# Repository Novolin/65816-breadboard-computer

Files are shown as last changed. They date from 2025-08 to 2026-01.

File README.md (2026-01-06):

# 65816-breadboard-computer
My Personal 65C816 breadboard build, including schematics, etc.

/KiCad contains my schematics/raw kicad files, if you want to laugh at my design.

/Software contains the programs I've written, mostly raw assembly, but I will hopefully have a C compiler up and running eventually.

/Docs will have a variety of documents on the exact nature of each hardware decision and how it works. I'll also be publishing these to a blog on my web zone. 

# Hardware Description:

This system is designed to use modular components, with room for expansion in RAM or I/O, using programmable logic. 

The primary CPU is a W65C816, which handles all logic/program execution. The "Bare Minimum" setup includes 32k of RAM and 32K of ROM space, both of which are placed on the primary controller board. The CPU is driven to 1 MHz by a divided clock oscillator, which provides a 2-phase clock signal, for any devices that may need it.

Expansion is handled through a 2x20 pin slot, so I can use a standard floppy drive cable to send it to a breakout board or other device.

## Graphical Output:

Despite my original intentions to use a z80 to drive a 320x240 display via weird magic bullshit, I have decided to switch to having the CPU directly control the display via the VIA's PORTB, though I will be sharing this with the 16x2 LCD thanks to some Ideas about how to handle I/O. See Docs/Displays for details.

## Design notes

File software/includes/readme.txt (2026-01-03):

This folder contains modules designed for individual components of the build

Remember to check the addresses defined in the structs in each file! Make sure they match real hardware!!

I am using CA65 as my assembler, so code is formatted for that. I'll write a lil baby script to compile on linux, at some point.

IOMEM only goes up to $01800F, the top address of the ACIA.

reminder: update schematic to include the vrom chip!!

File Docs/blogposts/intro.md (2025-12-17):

# 65C816-Based Homebrew Computer! Part one: The beginnings.

I've been following Ben Eater's 6502 homebrew computer[LINK] for a while, and wanted to do something similar myself. Upon discussing things in the Usagi Electric discord, I decided to use a W64C816S, the successor to the 6502, for a few reasons. First of all: it should be drop-in compatible with Ben's design (at least the early stages). Once I get my feet wet, I can branch out and do a lot more. Secondly, getting a 6502 would have been a whopping $2 less than an '816, so I might as well get the more powerful option, and have room to grow and play around.

## Goals:
At the start, my goals were vague, just to make something that worked, but now I've solidified on a concept:
1. Have a functional computer 
2. Allow connection via serial to another system
3. Have a graphical and text display
4. Enable future expansion/tinkering
    - Human Interface Devices of some form
    - Swapping of graphics/serial/whatevs
5. Get some PCBs made.

### Goal 1: Have a functioning computer.
This is a simple ask: it should be able to run the code that is placed on it, and do stuff. I'm not asking for perfection, but just for it to work. Arguably, this is the hardest part to actually achieve.

### Goal 2: Serial Connections
I want to communicate with the computer beyond inserting a new ROM chip, allowing for new programs/etc. A serial connection, using the 65C51 SIA is the best option, since it's in the ecosystem and has good documentation available for it. While using an RS-232 port and UART-to-usb or whatever is an option if I wanted to keep the hardware Authentic, I'm going to be lazy and just use an Arduino Micro as a USB serial adapter. This eases the adapter headaches, since it's able to do the USB -> serial translation, and it's cheap. If I get bitten by the retro-communications bug, I can figure out some other adapter situation and drop it in for ease of use. 

### Goal 3: Graphical and Text Display
Having a system that communicates only via serial is not what I am hoping for with this project. I want to be able to see/read things on a screen, and I purchased a 20x4 LCD display for this project, and repurposed a 320x240 LCD that I've had kicking around for graphical stuff. I've had a few ideas that went bust on this front, and I'll write them up at some point.

### Goal 4: Enable Future Expansion
Making a one-and-done system is a fun project, but I am unable to truly "finish" anything, so my way out for this is to have expansion buses on the system, allowing for more storage, devices, interfaces, etc. These buses will have access to the main CPU lines that I'll need, as well as address/data lines. Since I'm using Programmable Logic Devices as bus controllers, it's easy enough to daisy-chain my ports if needed.

### Goal 5: Get PCBs made
I've never designed a PCB. I did get some made using an open-source design once, but this is a new opportunity for me to expand my skillset, and experiment. It's a scary step, and not the cheapest, but I'm excited to do it. I'll likely use a manufacturing service, instead of etching/machining my own, but even the design process has taught me a lot.
PCBs are also critical for future expansion, since there's only so many breadboards I can manage.

In the short term, my focus has been on the first goal, having *anything* functional, before moving on to dealing with the others. So far, it's eluded me, but I have a hardware tweak that I have yet to test, which should make things fully functional.

## Hardware
As I mentioned at the start, I'm using a W65C816 processor, both due to price similarity to the 6502, but also due to its 24-bit memory addressing.

The 6502 uses a 16-bit memory bus, allowing for up to 64 Kilobytes of addressible memory, be it RAM, ROM, I/O or other stuff. The '816 uses some funky timing and the 8-bit data lines to increase the bus width to 24 bits, allowing for 16 **Mega**bytes of address space. There are also a variety of changes to the processor architecture which allow for 16-bit math, and a number of other changes. I'm not a 6502/65816 wizard, I'm barely what you would call a beginner, but the '816 is just an improved processor at the end of the day.

RAM is currrently divided into 32K SRAM chips, HM62256 clones from Aliexpress, and my total of 5 chips should lead to about 160 Kb of RAM total, which is more than enough for what I'm doing at the moment. 

My ROM is an AT28C256, also off Aliexpress, giving 32K of ROM space. With the addition of serial communications, this should be more than enough to handle the code needed to get things loaded into RAM.

Logic switching is handled by an AT16V8B, a derivitive of the GAL16V8B Programmable Logic Device (PLD). Why PLDs, instead of 74XX logic? Early experiments with graphics adapters led to me needing the ability to latch various control signals, and - once again - sourcing some chips from Aliexpress meant getting 5 of the dang things, so I might as well switch to using 'em. This also eases the burden on addressing expansion signals, since a simple re-flash is all it takes to change the routing (though PLDs do have a limited life-span, and I'll try to avoid re-flashing if possible.)
After a few expansions, it becomes messy as hell to use discrete logic ICs for each change, and that's not something I felt like playing with, especially since early prototyping meant limited breadboard space.

My clock oscillator runs at 16 MHz, which I am dividing three times to bring it to a more managable 2 MHz. I will be able to speed things up in the future, but this should be more than enough for anything I'm planning on.

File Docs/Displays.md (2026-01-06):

# Displays:

There are two displays connected to this system. One is a 320x240 LCD display, connected via SPI, and the other is a 20x4 character display, connected via parallel.

## Display Selection:

Display output is selected using i/o PORTA, with the lower nibble handling the control signals for the text display, and the uppper nibble controlling the graphical display. The plan (as it exists now) is to use defined shortcuts for each type of command, to ensure they do not overlap.

PORTB will send data to the LCD, using the 8-bit communication mode. I may change this in the future to be the 4-bit mode and then I can free up another port for other things.

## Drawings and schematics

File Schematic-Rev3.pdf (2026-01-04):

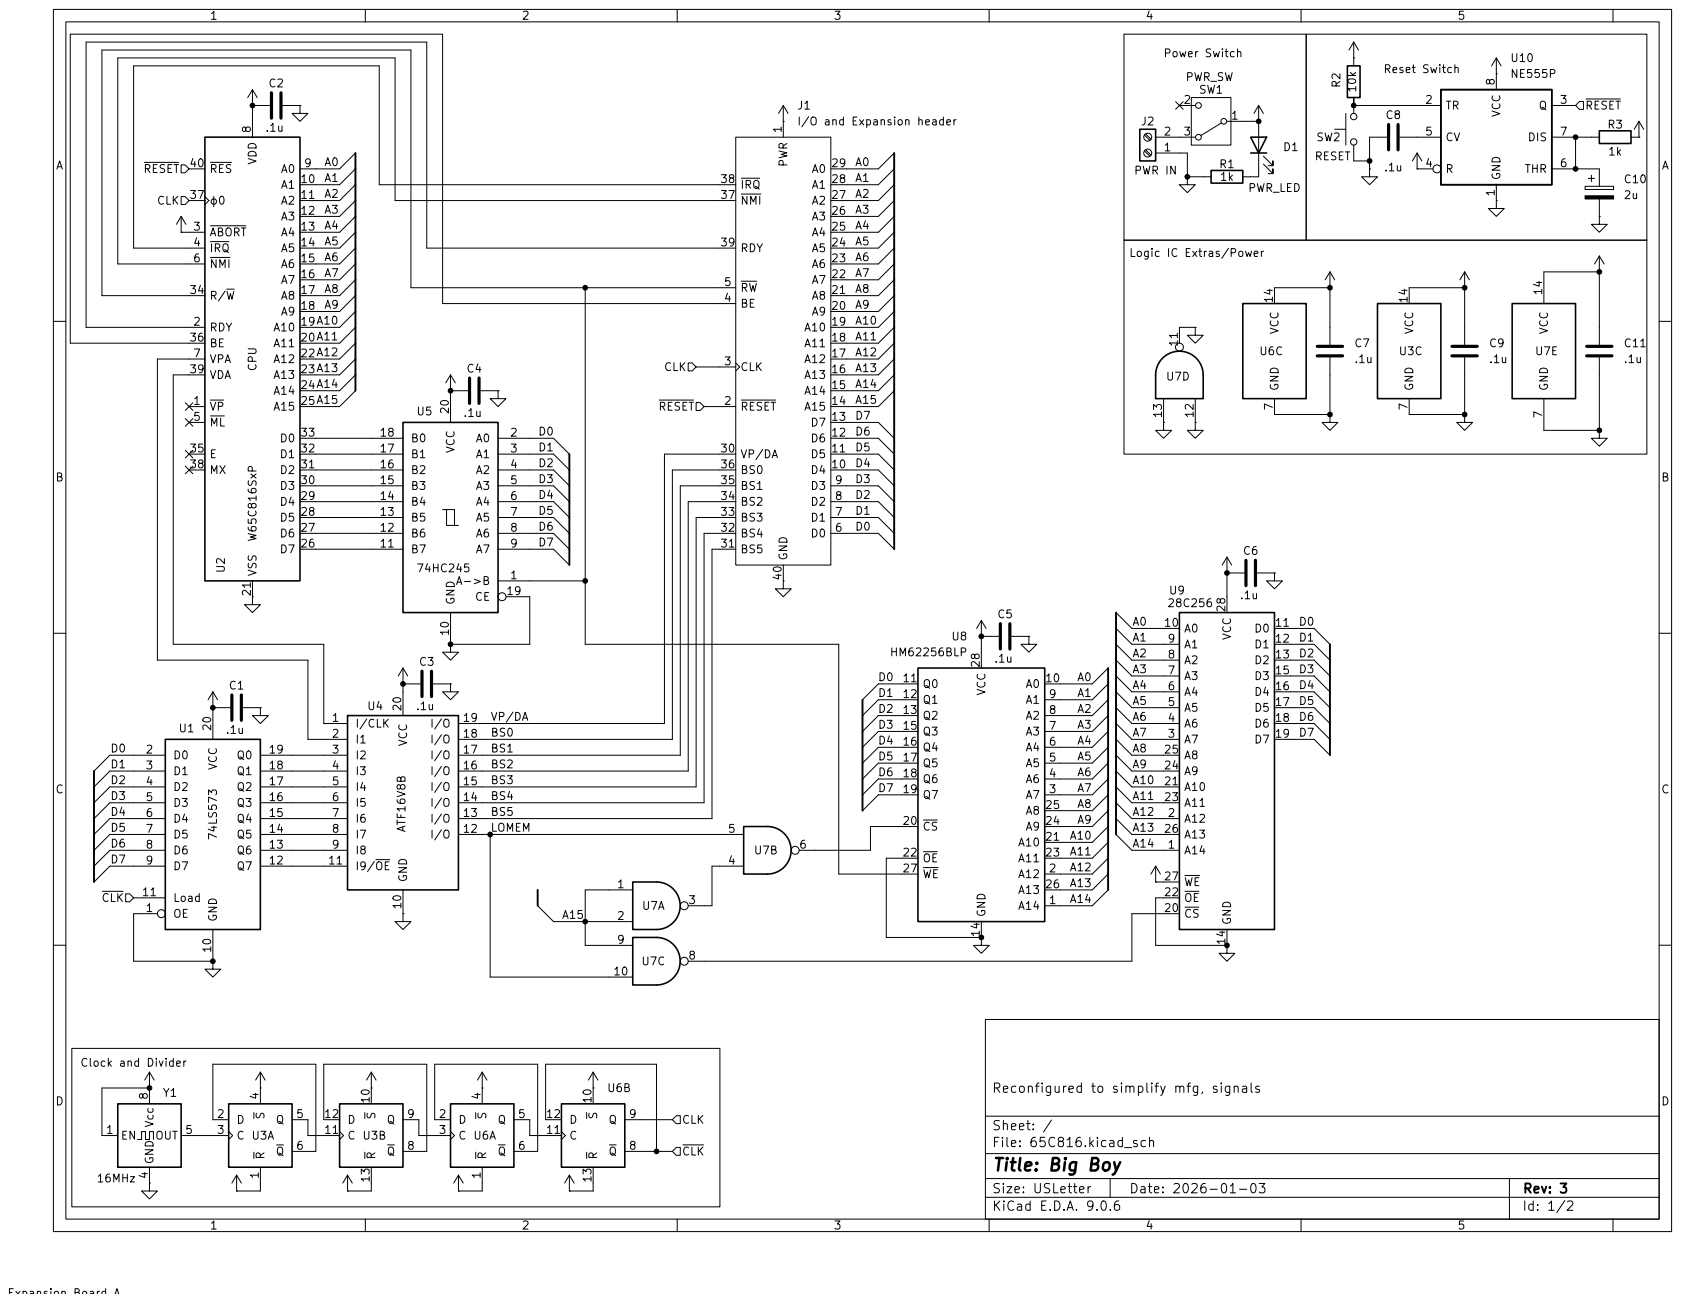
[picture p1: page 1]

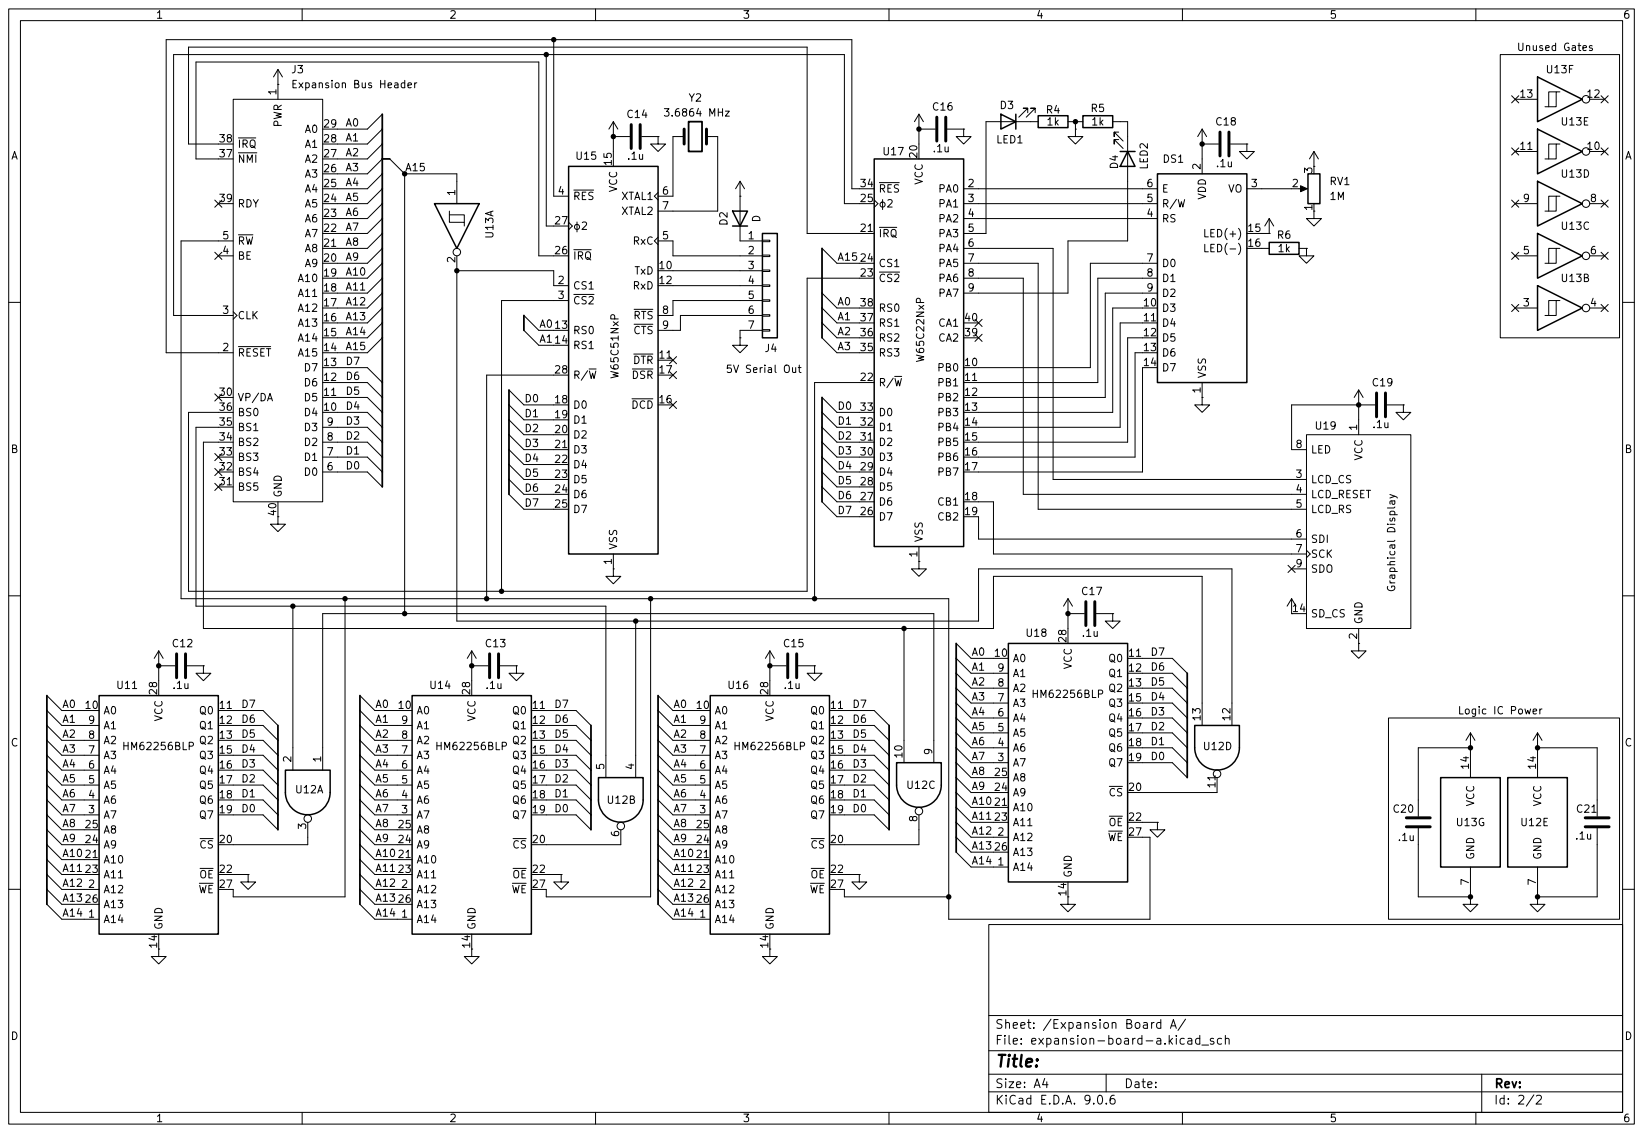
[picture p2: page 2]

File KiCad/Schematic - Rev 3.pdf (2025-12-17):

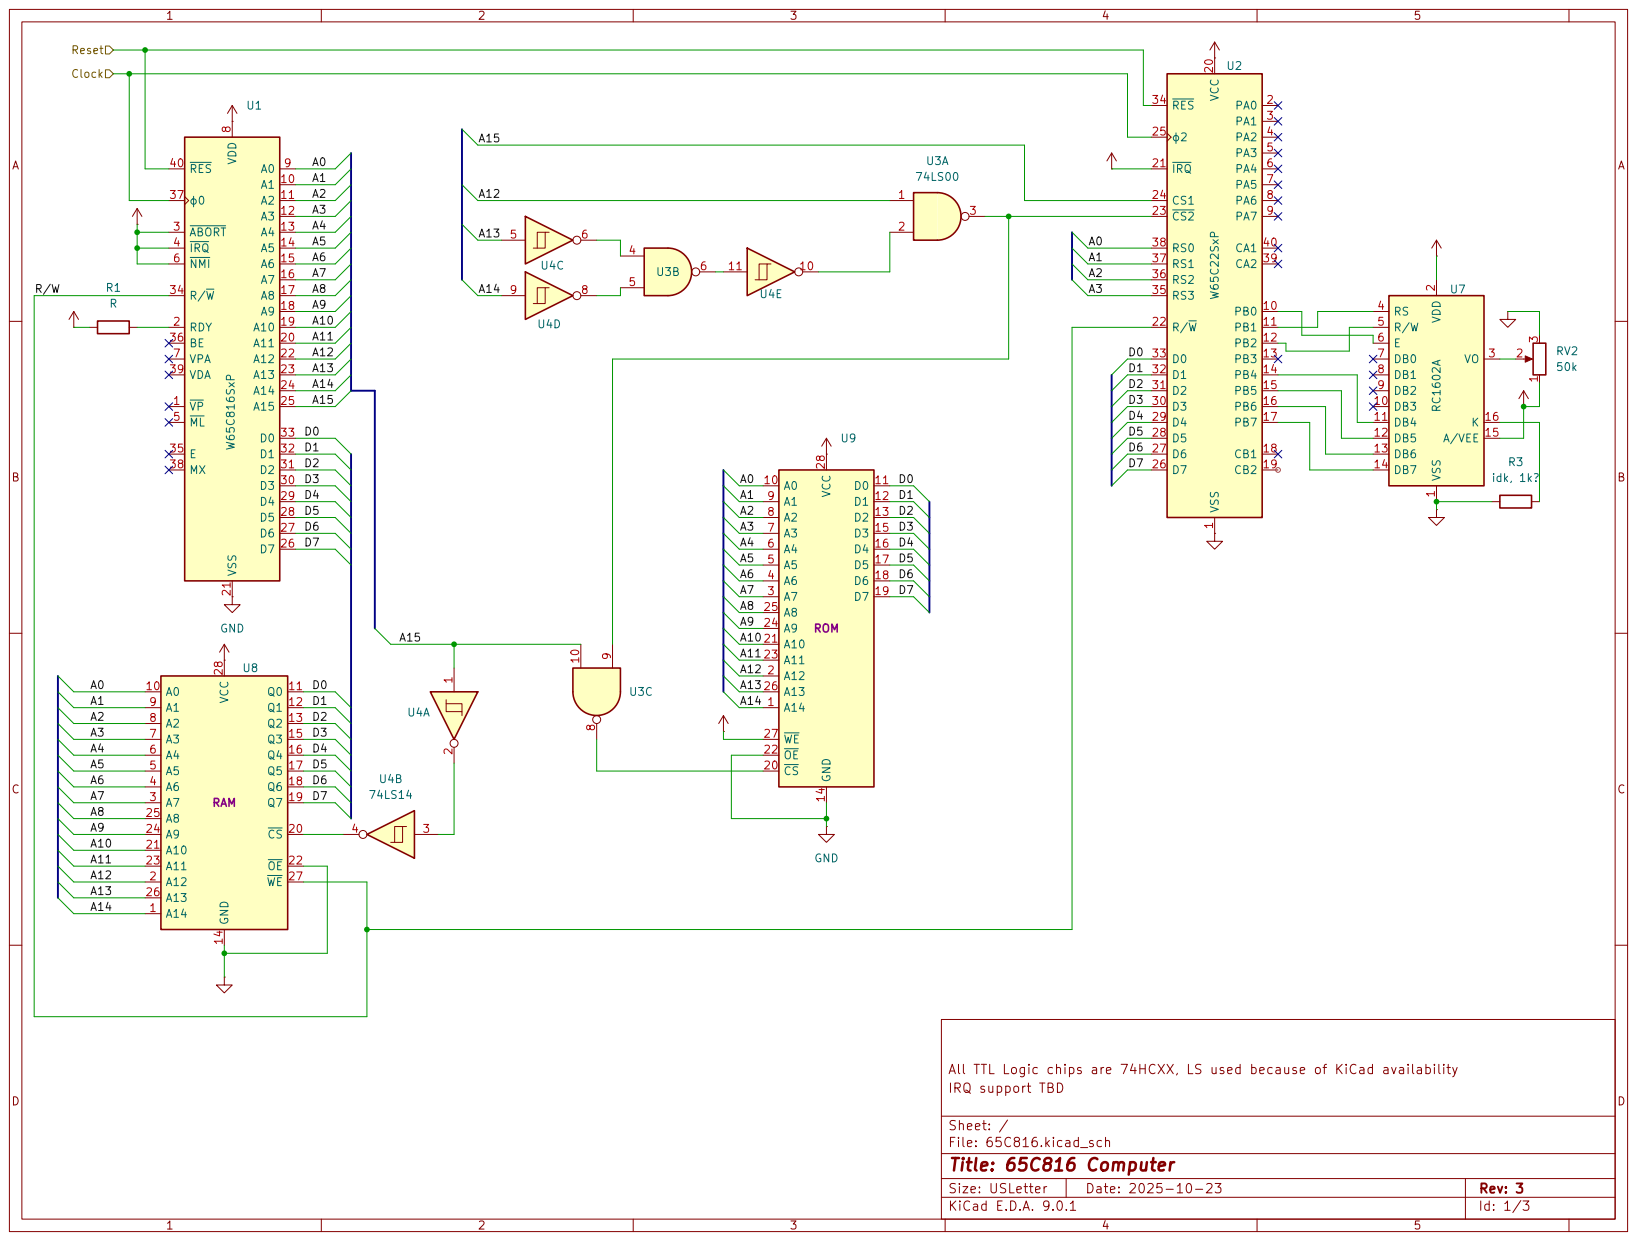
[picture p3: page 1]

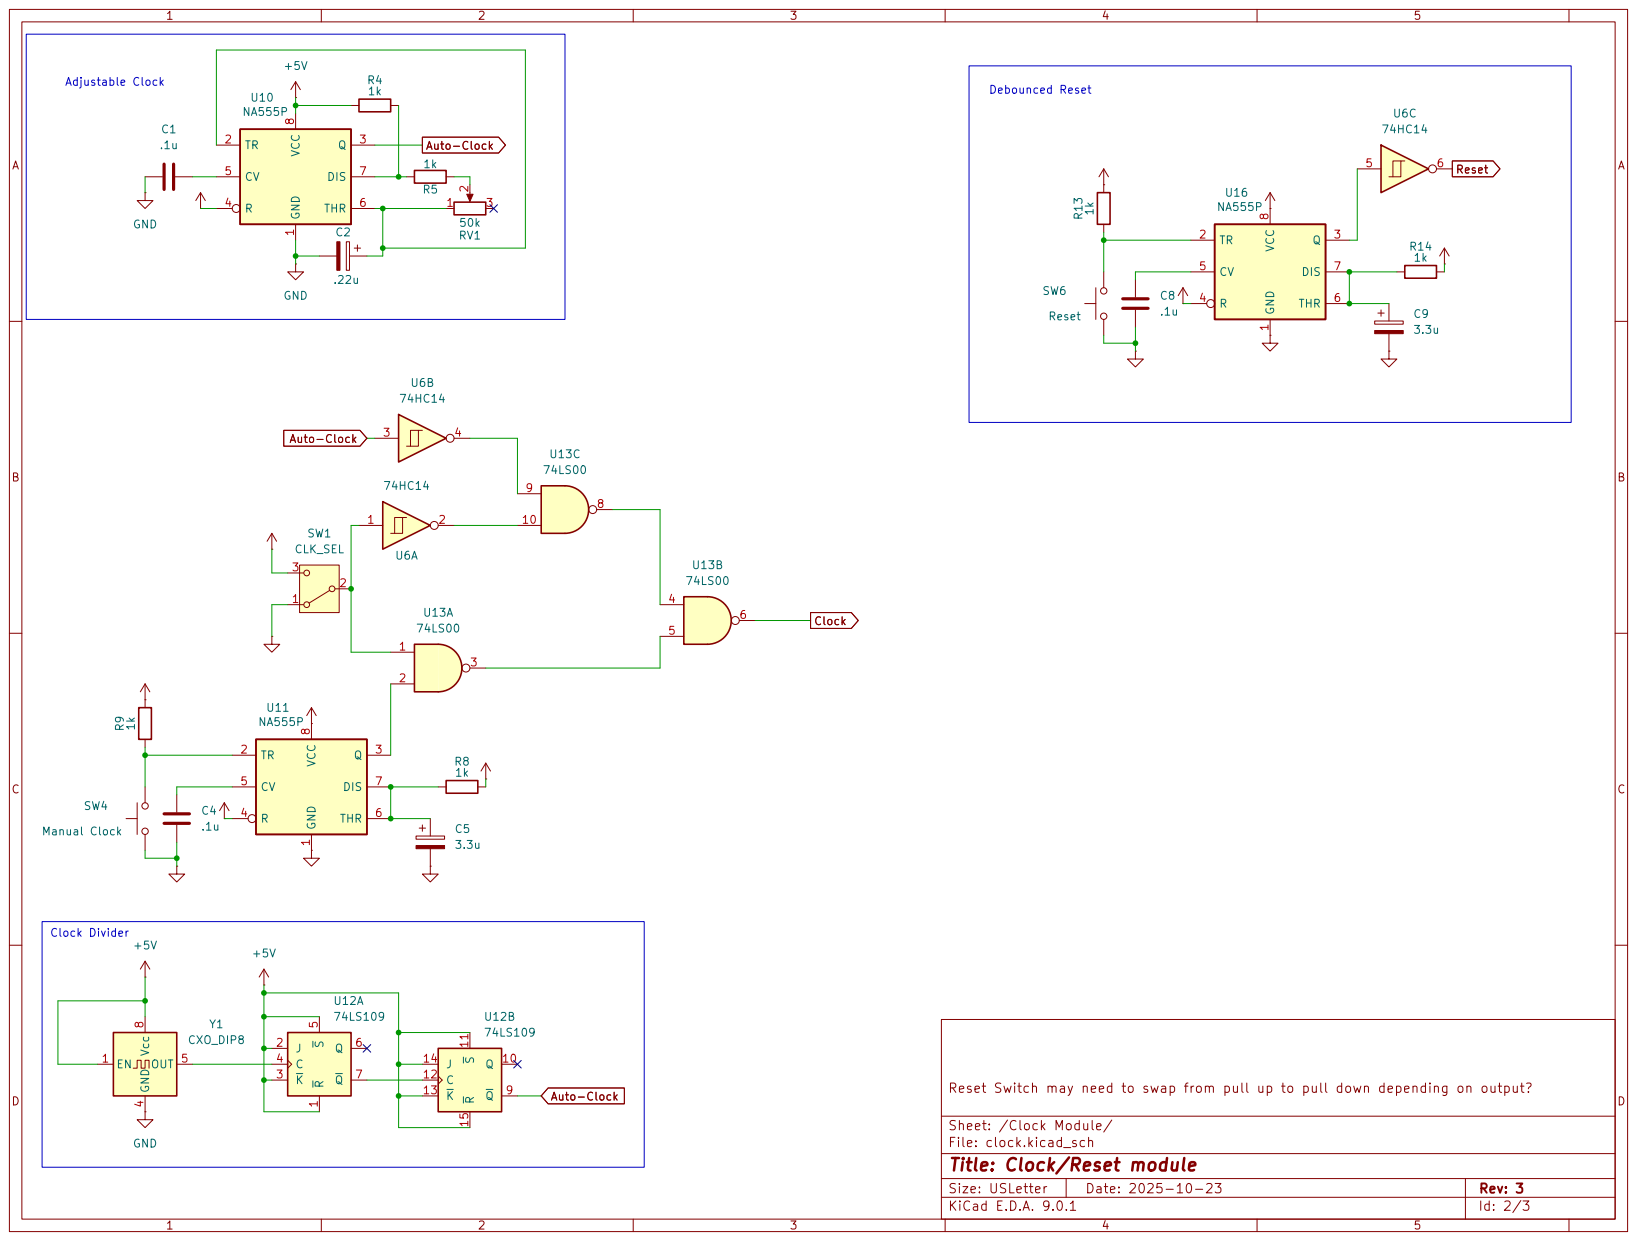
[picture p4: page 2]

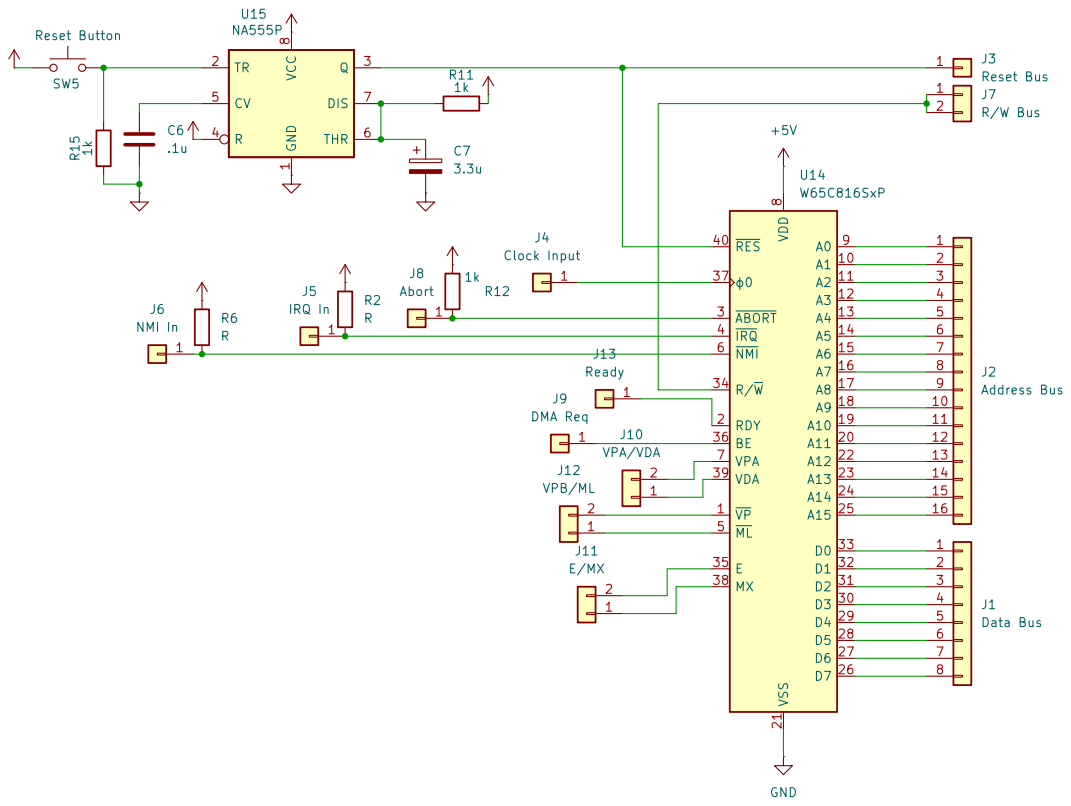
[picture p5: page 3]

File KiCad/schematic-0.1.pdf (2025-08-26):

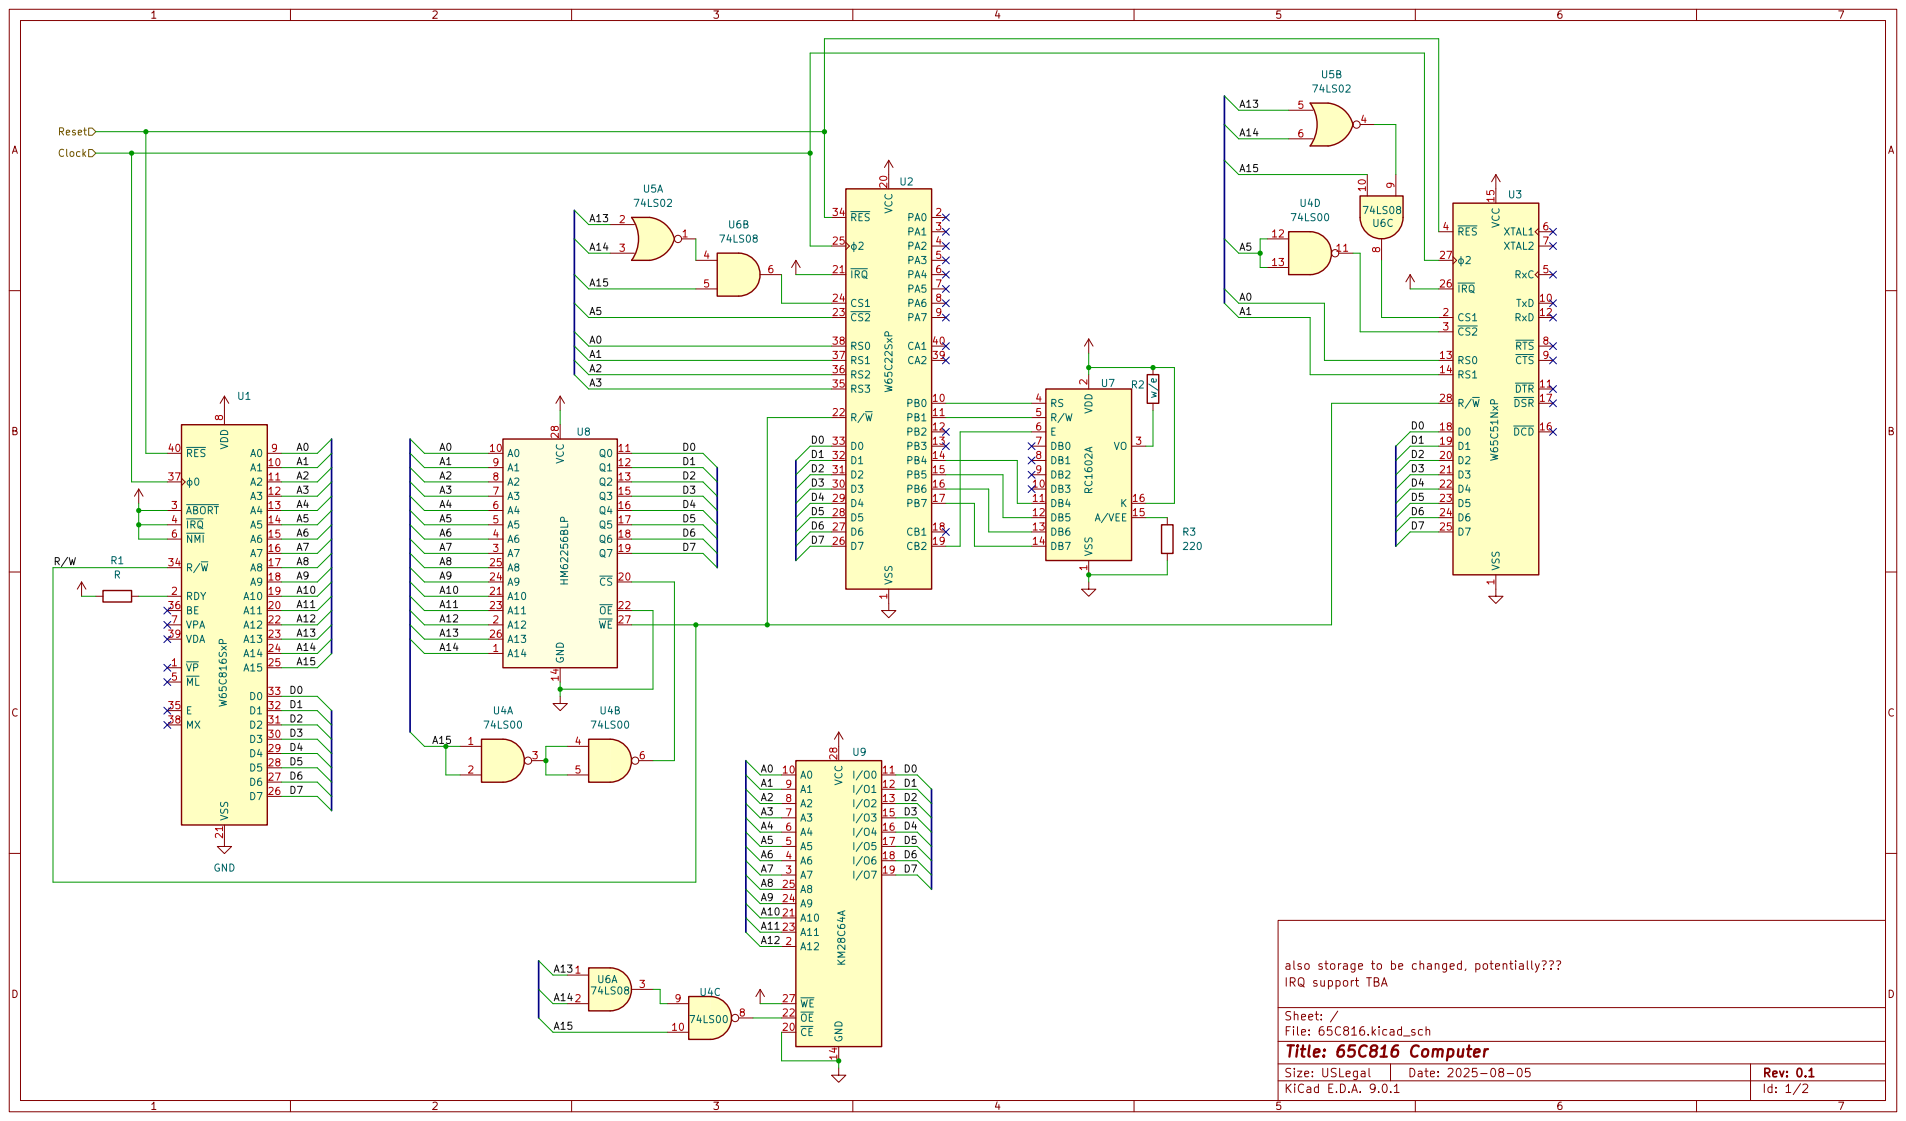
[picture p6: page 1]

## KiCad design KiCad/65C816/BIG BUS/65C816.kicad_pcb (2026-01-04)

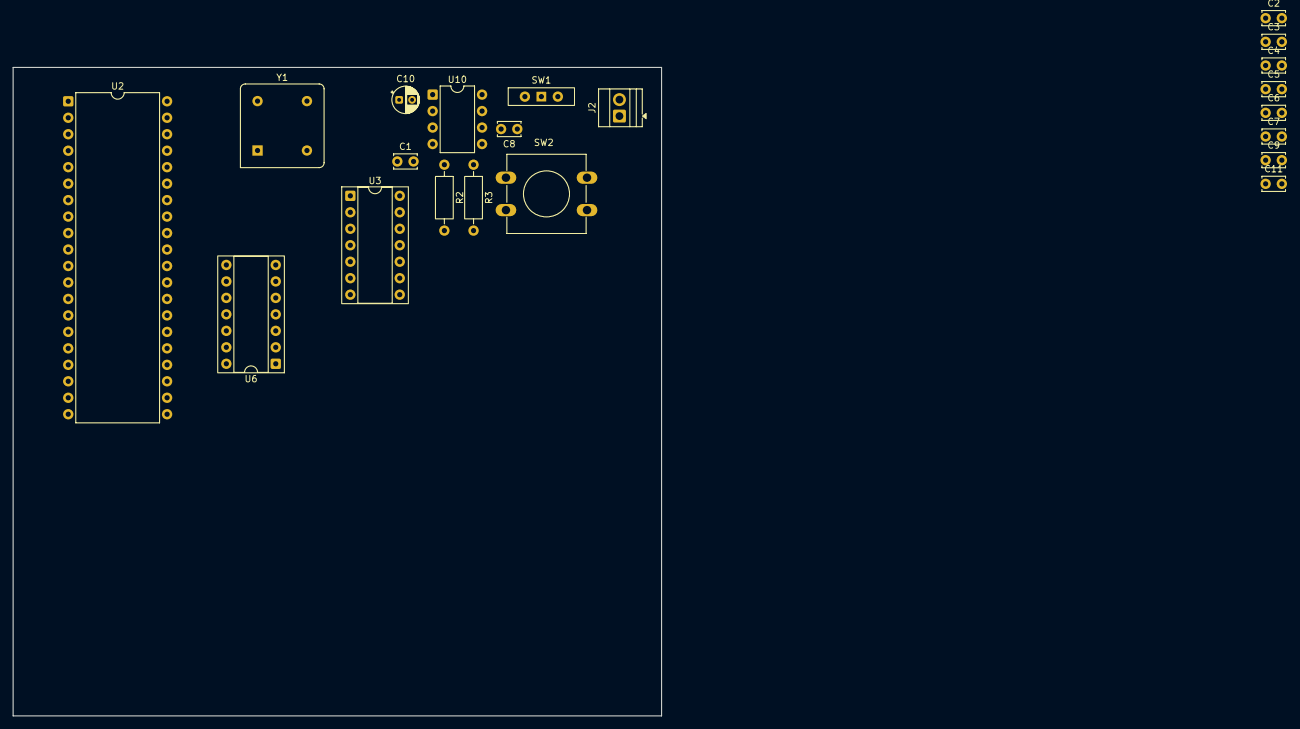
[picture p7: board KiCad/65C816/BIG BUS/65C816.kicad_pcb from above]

Board: 2 copper layers, 100.0 x 100.0 mm, 21 parts (0 on the bottom side), 16 nets, no tracks yet.

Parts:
C1, C2, C3, C4, C5, C6, C7, C8, C9, C11: .1u; C_Disc_D3.4mm_W2.1mm_P2.50mm
C10: 2u; CP_Radial_D4.0mm_P2.00mm
J2: PWR IN; TerminalBlock_Xinya_XY308-2.54-2P_1x02_P2.54mm_Horizontal
R2: 10k; R_Axial_DIN0207_L6.3mm_D2.5mm_P10.16mm_Horizontal
R3: 1k; R_Axial_DIN0207_L6.3mm_D2.5mm_P10.16mm_Horizontal
SW1: PWR_SW; SW_Slide-03_Wuerth-WS-SLTV_10x2.5x6.4_P2.54mm
SW2: RESET; SW_PUSH-12mm
U2: W65C816SxP; DIP-40_W15.24mm
U3, U6: 74HC74; DIP-14_W7.62mm_Socket
U10: NE555P; DIP-8_W7.62mm
Y1: 16MHz; Oscillator_DIP-8

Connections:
+5V: C1.1, C2.1, C3.1, C4.1, C5.1, C6.1, C7.1, C9.1, C11.1, R2.2, R3.2, SW1.1 (B), U2.3 (~ABORT), U2.8 (VDD), U3.1 (~R), U3.4 (~S), U3.10 (~S), U3.13 (~R), U3.14 (VCC), U6.1 (~R), U6.4 (~S), U6.10 (~S), U6.13 (~R), U6.14 (VCC), U10.4 (R), U10.8 (VCC), Y1.1 (EN), Y1.8 (Vcc)
/CLK: U2.37 (ϕ0), U6.9 (Q)
/~CLK: U6.8 (~Q), U6.12 (D)
/~RESET: U2.40 (~RES), U10.3 (Q)
GND: C1.2, C2.2, C3.2, C4.2, C5.2, C6.2, C7.2, C8.1, C9.2, C10.2, C11.2, J2.1, SW2.1, U2.21 (VSS), U3.7 (GND), U6.7 (GND), U10.1 (GND), Y1.4 (GND)
unnamed: J2.2, SW1.3 (A)
unnamed: U3.3 (C), Y1.5 (OUT)
unnamed: U3.2 (D), U3.6 (~Q)
unnamed: U3.5 (Q), U3.11 (C)
unnamed: U3.8 (~Q), U3.12 (D)
unnamed: U3.9 (Q), U6.3 (C)
unnamed: U6.2 (D), U6.6 (~Q)
unnamed: U6.5 (Q), U6.11 (C)
unnamed: C8.2, U10.5 (CV)
unnamed: C10.1, R3.1, U10.6 (THR), U10.7 (DIS)
unnamed: R2.1, SW2.2, U10.2 (TR)

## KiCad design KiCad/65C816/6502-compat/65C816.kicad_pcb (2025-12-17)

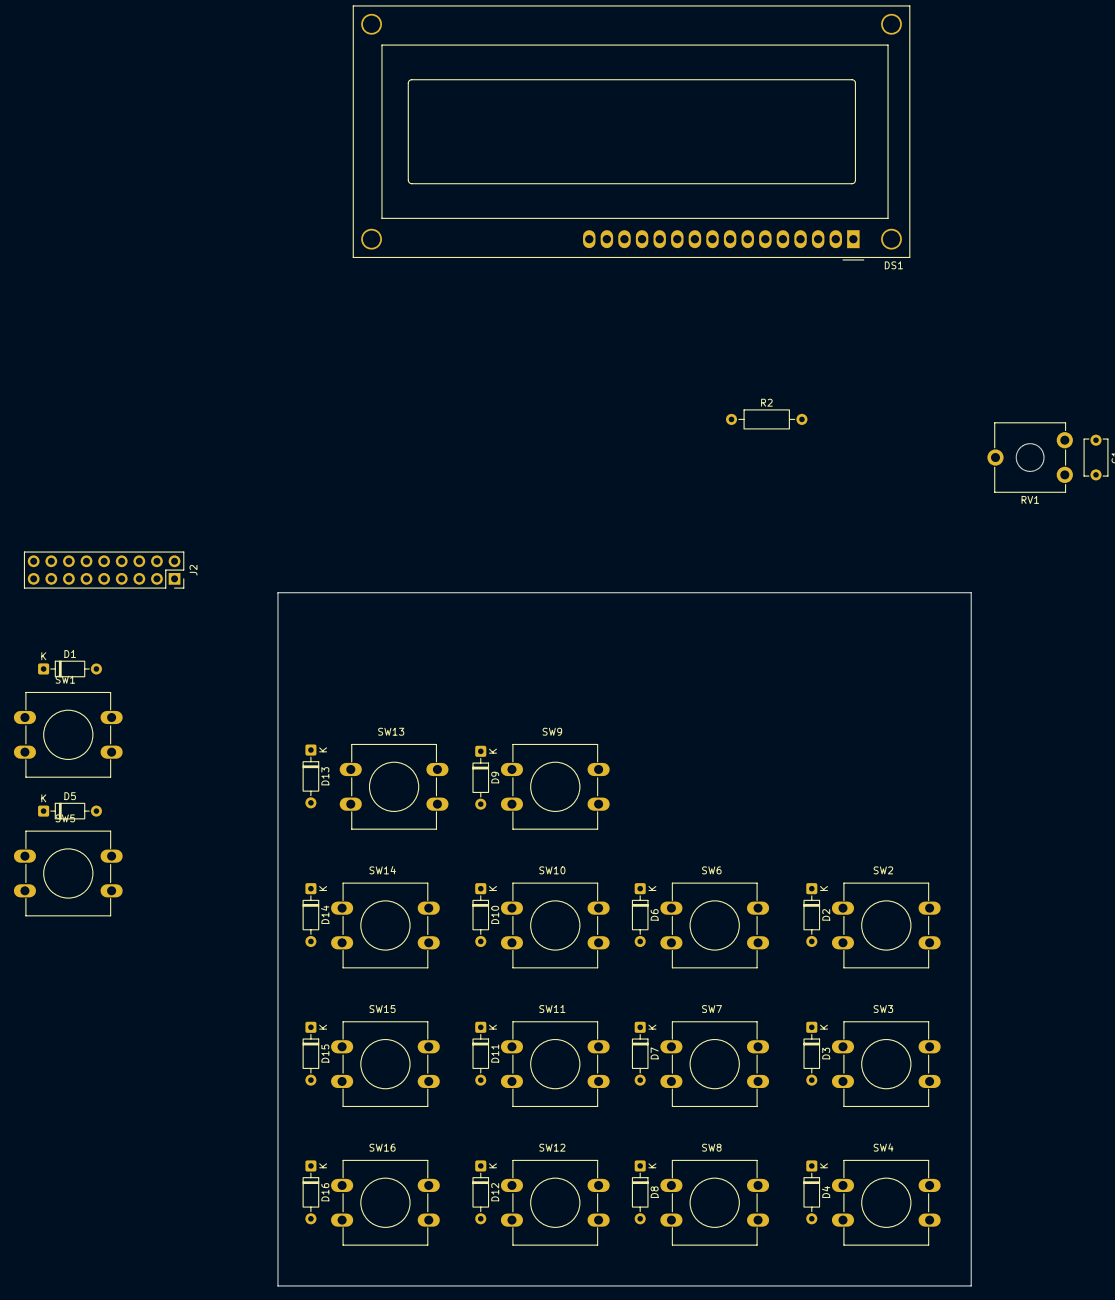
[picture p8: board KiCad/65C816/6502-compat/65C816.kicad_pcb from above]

Board: 2 copper layers, 100.0 x 100.0 mm, 37 parts (0 on the bottom side), 35 nets, no tracks yet.

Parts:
C1: .1u; C_Disc_D5.1mm_W3.2mm_P5.00mm
D1, D2, D3, D4, D5, D6, D7, D8, D9, D10, D11, D12, D13, D14, D15, D16: D; D_DO-35_SOD27_P7.62mm_Horizontal
DS1: WC1602A
J2: Conn_02x09_Top_Bottom; PinSocket_2x09_P2.54mm_Vertical
R2: 680; R_Axial_DIN0207_L6.3mm_D2.5mm_P10.16mm_Horizontal
RV1: 1M; Potentiometer_ACP_CA9-V10_Vertical_Hole
SW1: A1; SW_PUSH-12mm
SW2: B1; SW_PUSH-12mm
SW3: C1; SW_PUSH-12mm
SW4: D1; SW_PUSH-12mm
SW5: A2; SW_PUSH-12mm
SW6: B2; SW_PUSH-12mm
SW7: C2; SW_PUSH-12mm
SW8: D2; SW_PUSH-12mm
SW9: A3; SW_PUSH-12mm
SW10: B3; SW_PUSH-12mm
SW11: C3; SW_PUSH-12mm
SW12: D3; SW_PUSH-12mm
SW13: A4; SW_PUSH-12mm
SW14: B4; SW_PUSH-12mm
SW15: C4; SW_PUSH-12mm
SW16: D4; SW_PUSH-12mm

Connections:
+5V: C1.2, DS1.2 (VDD), DS1.15 (LED(+)), J2.10, RV1.3
GND: C1.1, DS1.1 (VSS), J2.1, R2.1, RV1.1
unnamed: D1.2 (A), SW1.2
unnamed: D1.1 (K), D5.1 (K), D9.1 (K), D13.1 (K), J2.6
unnamed: D2.2 (A), SW2.2
unnamed: D3.2 (A), SW3.2
unnamed: D4.2 (A), SW4.2
unnamed: D5.2 (A), SW5.2
unnamed: D6.2 (A), SW6.2
unnamed: D7.2 (A), SW7.2
unnamed: D8.2 (A), SW8.2
unnamed: D9.2 (A), SW9.2
unnamed: D10.2 (A), SW10.2
unnamed: D2.1 (K), D6.1 (K), D10.1 (K), D14.1 (K), J2.7
unnamed: D11.2 (A), SW11.2
unnamed: D3.1 (K), D7.1 (K), D11.1 (K), D15.1 (K), J2.8
unnamed: D12.2 (A), SW12.2
unnamed: D4.1 (K), D8.1 (K), D12.1 (K), D16.1 (K), J2.9
unnamed: D13.2 (A), SW13.2
unnamed: D14.2 (A), SW14.2
unnamed: D15.2 (A), SW15.2
unnamed: D16.2 (A), SW16.2
unnamed: DS1.11 (D4), J2.15
unnamed: DS1.12 (D5), J2.16
unnamed: DS1.13 (D6), J2.17
unnamed: DS1.14 (D7), J2.18
unnamed: DS1.6 (E), J2.11
unnamed: DS1.16 (LED(-)), R2.2
unnamed: DS1.4 (RS), J2.13
unnamed: DS1.5 (R/W), J2.12
unnamed: DS1.3 (VO), RV1.2
unnamed: J2.2, SW1.1, SW2.1, SW3.1, SW4.1
unnamed: J2.3, SW5.1, SW6.1, SW7.1, SW8.1
unnamed: J2.4, SW9.1, SW10.1, SW11.1, SW12.1
unnamed: J2.5, SW13.1, SW14.1, SW15.1, SW16.1

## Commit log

2025-08-26 Added local files
    [65C816.kicad_pcb, 65C816.kicad_sch, 65C816v1.kicad_sch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]
2025-09-02 Uploaded data sheets, did some more programmer stuff. Also some assembly stuff.
2025-11-25 Whole bunch of stuff, removed EEPROM writer (i bought one sorry) and hella schematic changes
    [65C816.kicad_pcb, 65C816.kicad_sch, 65C816_breakout.kicad_sch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]
2025-11-27 Preliminary PLD stuff, state machines are scary
    [65C816.kicad_sch, Clock.kicad_sch, Serial.kicad_sch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]
2025-12-02 lots of stiff
    [65C816-B_Cu.gbr, 65C816-B_Mask.gbr, 65C816-B_Paste.gbr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]
2025-12-17 Cleaned up random files, added actual .gitignore on my end lmao
    [65C816.kicad_pcb, 65C816.kicad_sch, GFXv2.kicad_sch]
2025-12-23 Switched from vasm for compilation to CC65, since it has better '816 support, and I can start using C.
2026-01-02 forgot to stage this one too
2026-01-04 Schematic updates
    [65C816.kicad_pcb, 65C816.kicad_sch, expansion-board-a.kicad_sch]
